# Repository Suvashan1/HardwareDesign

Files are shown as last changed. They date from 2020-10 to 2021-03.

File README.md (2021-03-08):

# STM32 Breakout-Board using STM32F103C8T6 Microcontroller

Using this medium-density microcontroller, an experimental peripheral board was designed using KiCAD to validate PCB design principles that I have learnt. It has formed a template for future layouts and schematic designs. For further information on my design choices, method and components selected and their placement, please read the design-considerations PDF in the file.

# Layout:

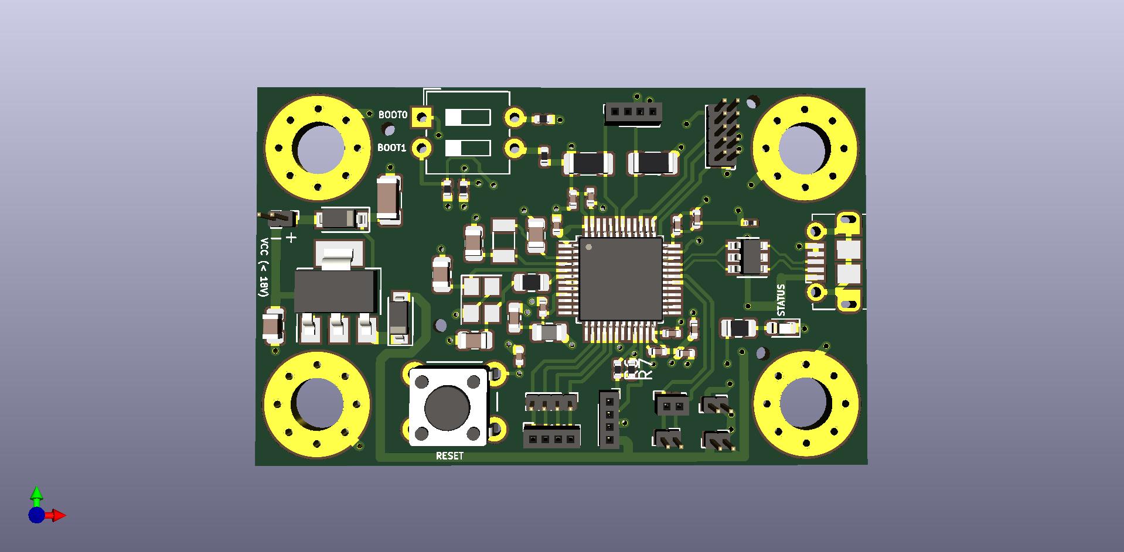
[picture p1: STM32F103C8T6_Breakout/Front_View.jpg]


# Schematic:

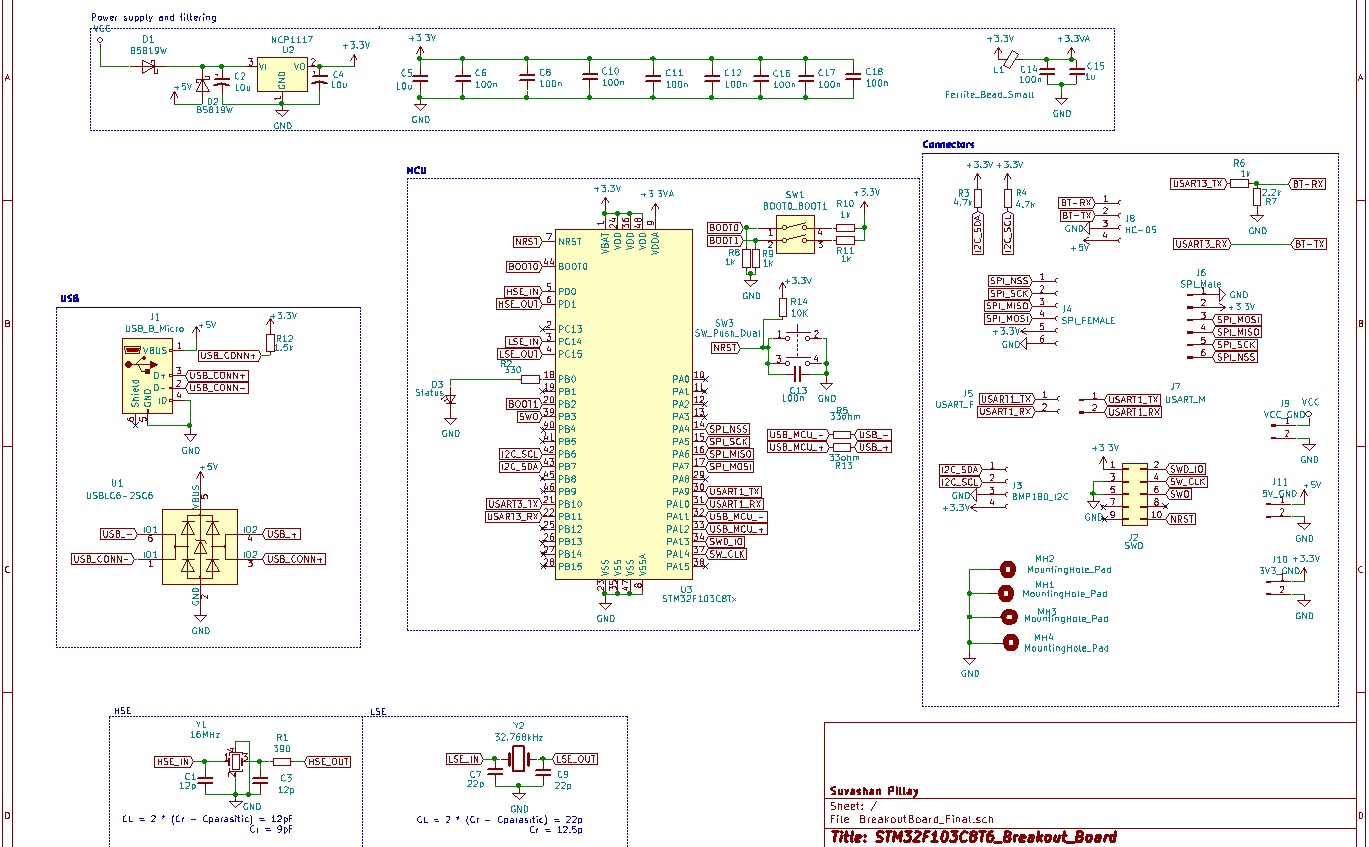
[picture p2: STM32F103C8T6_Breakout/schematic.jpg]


# BOSCH BMP180 Drivers

The following device drivers were developed to be used with the respective breakout board designed, to test the I2C interface. All instructions and files can be found in the folder
added.

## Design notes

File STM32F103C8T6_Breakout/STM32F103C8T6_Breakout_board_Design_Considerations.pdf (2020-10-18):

## STM32F103C8T6 Breakout board

### Aim

The purpose of the breakout board is to implement and/or tailor the firmware written in the "Driversfor-STM32-MCUs" repository (https://github.com/Suvashan1/Drivers-for-STM32-MCUs) on another microcontroller from ST Microelectronics and interface calibrated sensors such as the BMP180 pressure and temperature sensor, with communications interfaces. I have also aimed to present my skills in PCB (printed circuit board) design and assess my shortcomings as an engineer, to provide hardware design which is more efficient in future revisions. It is a PCB constructed entirely from scratch and serves to provide the same use as an Arduino nano or STM32 blue-pill, which are popular development boards used for prototyping with sensors.

### Microcontroller used and core components

- STM32F103C8T6 microcontroller from ST microelectronics – This microcontroller had been used, as it provides an adequate amount of basic communication peripherals (2 I2C peripherals of which 1 was used, 2 USART peripherals of which both were used, and 2 SPI peripherals of which 1 was used). These communication peripherals will allow adequate testing of the firmware written. Other interfaces such as CAN and I2S are usable on the microcontroller, for later revisions.
This series of microcontrollers are known as “mainstream performance line” by ST, as they use an ARM Cortex M3 processor, which is adequate for general usage, and cost-effective. Other microcontrollers were considered such as the STM32F407VGT6, which is native to the drivers already written, but are more expensive and requires more design considerations.
A USB 2.0 FS interface is also available on this microcontroller, allowing for USB further, but non-reliant, firmware development in the future. Essentially, one can still power the board and program it, without the use of USB, since there is provision for BOOTx (x = 1,2) mode changes. The board can be programmed via SWD (Serial-wire debug), which is an interface that has been accounted for.
- Power supply section and filtering – A 3.3V regulator (AMS1117) was used, for voltage supply of the microcontroller, from an input supply pin (allowing an input voltage from the user up to 18V). A Schottky diode was added at the input line of the regulator, and prevents any reverse bias connection, from the input supply, and an additional diode was added from a 5V line of the USB port.
According to the hardware design application note from ST (AN2586), one (typically two, as per consideration of further noise suppression) 100nF capacitor must be added for each VDD pin and a 10uF capacitor. Since we consider three VDD pins and a VBat (battery connection for the microcontroller, which should be connected to VDD if a battery is not intended), nine capacitors have been added, as a decoupling network. Decoupling and filtering for the VDDA(ADC voltage supply), had been considered, and referenced from AN2586. A ferrite bead has been added (600Ω @ 100MHz), with decoupling 100nF and 1uF capacitors, in connection to the VDD pin.
- USB implementation and ESD protection – Since USB functionality had been added, a USB-B micro had been chosen for aesthetic and size considerations. ESD protection has been added using a USBLC6-2SC6 IC. This prevents static discharge through the board.

- HSE (High-Speed External) and LSE (Low-Speed External) crystal oscillators – Both crystals (16MHz and 32.768kHz respectively) have been added, and their respective load capacitors added. Calculations of the capacitor values have been added on the schematic sheet, where the parasitic capacitance of the board had been chosen as 2pF. The LSE crystal allows the use of the RTC (Real-Time Clock) peripheral at another stage of development.
- BOOTx modes and RESET button – A 2-pole dip switch has been added to alter BOOT1 (PB2) and BOOT0 has been added. This allows the use of DFU Mode (Direct-Firmware Upgrade), where the microcontroller may be programmed directly by USART. The most popular mode of programming an ST microcontroller, is by using SWD, which is the alternative to DFU mode. A reset button has been added to provide an option to perform a hard reset on the microcontroller.

### Design considerations when drawing the schematic and component layout

- JLCPCB was the chosen fabrication service (PCBway was also considered but proved to be more expensive). A board of dimensions 50x50mm has a price of $5(R82) for a 4-layer PCB. Boards with larger dimensions fare worse in terms of cost, even if exceeded by 1mm. However, a larger board is never recommended, especially dealing with communications peripherals. A 50x31mm (L X B) board size has been used.
- Crystal oscillators, decoupling capacitors and USB had been placed closer to the microcontroller, than other peripherals. This prevents any harmonics from affecting those peripherals or the microcontroller. Schottky diodes of the power supply section specifically had also been placed further from the crystal oscillators, to prevent harmonics and electrical noise.
- A “drive-resistor” is added to the output pin of the HSE crystal oscillator on the microcontroller, to prevent the output pin from sinking excessive amounts of current and “over-driving” the crystal oscillator.
- Header pins of peripherals have been included, as close to the microcontroller as possible, and on the respective edges of their pins on the microcontroller.
- Components which could be recalculated and replaced if the peripheral proves to be problematic have been assigned larger PCB footprints, to provide easier reflow and handsoldering. Examples of these can be seen in the pcbnew file, where 1206 pull-up resistors have been used for the I2C peripheral, as the speed of the peripheral is influenced by these resistors and may be replaced. Through experimentation, 2.2kΩ and 4.7kΩ are standard values. The drive-resistor of the HSE crystal oscillator may also be replaced if the crystal cannot sustain oscillations. This may be monitored in software.
- An additional USART peripheral has been added to provide usage of the HC-05 bluetooth module (https://www.robotics.org.za/HC05-PINS), and the I2C peripheral uses a 4-pin header for the use of a BMP180 (https://www.mantech.co.za/ProductInfo.aspx?Item=15M2316) pressure sensor. These peripherals have been accounted for, to provide simplistic yet thorough testing. The HC-05 will be used to receive commands from a smartphone via Bluetooth and transmission of pressure readings from the BMP180 sensor may be processed, either transmission to the smartphone or using printf statement in the IDE.
- The 10-pin header chosen for use of the SWD interface, is to be used with a STM32F407VG-DISC1 development board which I own. This development board will serve as debugging probe via ST-LINK and allow for programming and debugging of the microcontroller.

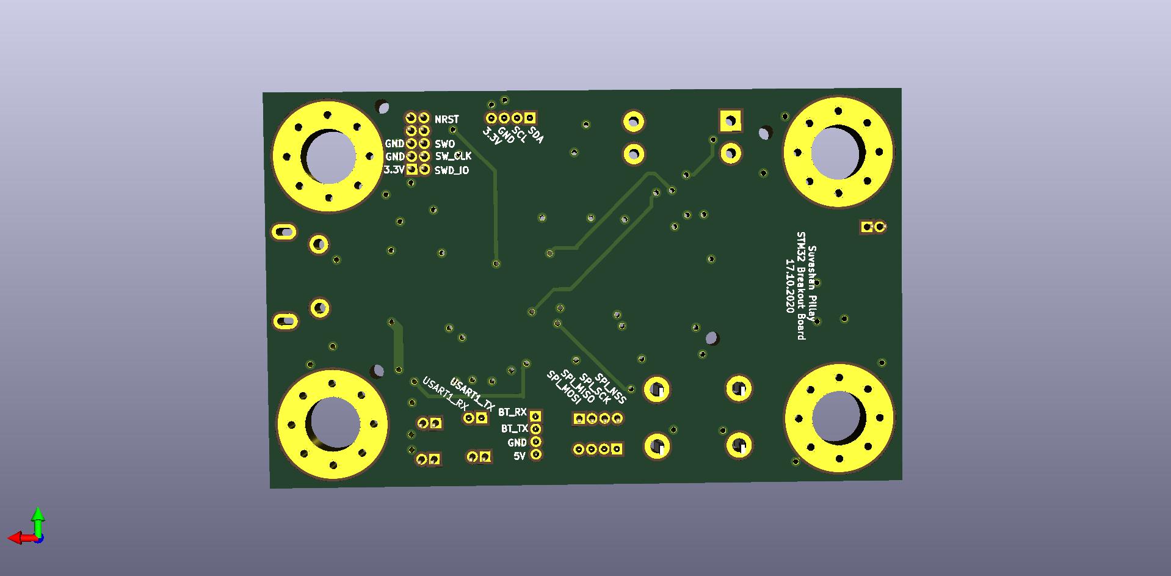
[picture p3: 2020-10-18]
STM32F103C8T6_Breakout/Rear_View.jpg

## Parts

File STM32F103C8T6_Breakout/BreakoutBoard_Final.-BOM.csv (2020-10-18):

Reference | Quantity | Value | Footprint | Datasheet | LCSC Part #
C15 | 1 | 1u | Capacitor_SMD:C_0603_1608Metric | ~ | C15849
C2 | 1 | 10u | Capacitor_SMD:C_1206_3216Metric | ~ | C13585
C1 C3 | 2 | 12p | Capacitor_SMD:C_0805_2012Metric | ~ | C1792
C4 | 1 | 10u | Capacitor_SMD:C_0805_2012Metric | ~ | C15850
C5 | 1 | 10u | Capacitor_SMD:C_0402_1005Metric | ~ | C15525
C10 C11 C12 C13 C14 C16 C17 C18 C6 C8 | 10 | 100n | Capacitor_SMD:C_0402_1005Metric | ~ | C1525
C7 C9 | 2 | 22p | Capacitor_SMD:C_0805_2012Metric | ~ | C1804
D1 D2 | 2 | B5819W | Diode_SMD:D_SOD-123 | ~ | C8598
D3 | 1 | Status | LED_SMD:LED_0603_1608Metric | ~ | C72041
J1 | 1 | USB_B_Micro | Connector_USB:USB_Micro-B_Molex-105017-0001 | ~
J10 | 1 | 3V3_GND | Connector_PinHeader_1.00mm:PinHeader_1x02_P1.00mm_Vertical | ~
J11 | 1 | 5V_GND | Connector_PinHeader_1.00mm:PinHeader_1x02_P1.00mm_Vertical | ~
J2 | 1 | SWD | Connector_PinHeader_1.00mm:PinHeader_2x05_P1.00mm_Vertical | ~
J3 | 1 | BMP180_I2C | Connector_PinSocket_1.00mm:PinSocket_1x04_P1.00mm_Vertical | ~
J4 | 1 | SPI_F | Connector_PinSocket_1.00mm:PinSocket_1x04_P1.00mm_Vertical | ~
J5 | 1 | USART_F | Connector_PinSocket_1.00mm:PinSocket_1x02_P1.00mm_Vertical | ~
J6 | 1 | SPI_M | Connector_PinHeader_1.00mm:PinHeader_1x04_P1.00mm_Vertical | ~
J7 | 1 | USART_M | Connector_PinHeader_1.00mm:PinHeader_1x02_P1.00mm_Vertical | ~
J8 | 1 | HC-05 | Connector_PinSocket_1.00mm:PinSocket_1x04_P1.00mm_Vertical | ~
J9 | 1 | VCC_GND | Connector_PinHeader_1.00mm:PinHeader_1x02_P1.00mm_Vertical | ~
L1 | 1 | Ferrite_Bead_Small | Inductor_SMD:L_0805_2012Metric | ~ | C1017
MH1 MH2 MH3 MH4 | 4 | MountingHole_Pad | MountingHole:MountingHole_4.3mm_M4_Pad_Via | ~
R1 | 1 | 390 | Resistor_SMD:R_0805_2012Metric | ~ | C17655
R12 | 1 | 1.5k | Resistor_SMD:R_0201_0603Metric | ~ | C22483
R2 | 1 | 33ohm | Resistor_SMD:R_0805_2012Metric | ~ | C17634
R3 R4 | 2 | 4.7k | Resistor_SMD:R_1206_3216Metric | ~ | C17936
R10 R11 R6 R8 R9 | 5 | 1k | Resistor_SMD:R_0402_1005Metric | ~ | C11702
R7 | 1 | 2.2k | Resistor_SMD:R_0402_1005Metric | ~ | C25879
SW1 | 1 | BOOT0_BOOT1 | Button_Switch_THT:SW_DIP_SPSTx02_Slide_6.7x6.64mm_W7.62mm_P2.54mm_LowProfile
SW3 | 1 | SW_Push_Dual | Button_Switch_THT:SW_PUSH_6mm
U1 | 1 | USBLC6-2SC6 | Package_TO_SOT_SMD:SOT-23-6 | http://www2.st.com/resource/en/datasheet/CD00050750.pdf | C7519
U2 | 1 | NCP1117 | Package_TO_SOT_SMD:SOT-223-3_TabPin2 | http://www.onsemi.com/pub_link/Collateral/NCP1117-D.PDF | C6186
U3 | 1 | STM32F103C8Tx | Package_QFP:LQFP-48_7x7mm_P0.5mm | http://www.st.com/st-web-ui/static/active/en/resource/technical/document/datasheet/CD00161566.pdf | C8734
Y1 | 1 | 16MHz | Crystal:Crystal_SMD_3225-4Pin_3.2x2.5mm | ~ | C13738
Y2 | 1 | 32.768kHz | Crystal:Crystal_SMD_3215-2Pin_3.2x1.5mm | ~ | C32346

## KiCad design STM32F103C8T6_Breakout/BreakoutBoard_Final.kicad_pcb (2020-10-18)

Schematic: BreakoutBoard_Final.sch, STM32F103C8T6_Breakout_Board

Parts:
C1, C3: 12p; C_0805_2012Metric; LCSC Part # C1792
C2: 10u; C_1206_3216Metric; LCSC Part # C13585
C4: 10u; C_0805_2012Metric; LCSC Part # C15850
C5: 10u; C_0402_1005Metric; LCSC Part # C15525
C6, C8, C10, C11, C12, C13, C14, C16, C17, C18: 100n; C_0402_1005Metric; LCSC Part # C1525
C7, C9: 22p; C_0805_2012Metric; LCSC Part # C1804
C15: 1u; C_0603_1608Metric; LCSC Part # C15849
D1, D2: B5819W; D_SOD-123; LCSC Part # C8598
D3: Status; LED_0603_1608Metric; LCSC Part # C72041
J1: USB_B_Micro; USB_Micro-B_Molex-105017-0001
J2: SWD; PinHeader_2x05_P1.00mm_Vertical
J3: BMP180_I2C; PinSocket_1x04_P1.00mm_Vertical
J4: SPI_F; PinSocket_1x04_P1.00mm_Vertical
J5: USART_F; PinSocket_1x02_P1.00mm_Vertical
J6: SPI_M; PinHeader_1x04_P1.00mm_Vertical
J7: USART_M; PinHeader_1x02_P1.00mm_Vertical
J8: HC-05; PinSocket_1x04_P1.00mm_Vertical
J9: VCC_GND; PinHeader_1x02_P1.00mm_Vertical
J10: 3V3_GND; PinHeader_1x02_P1.00mm_Vertical
J11: 5V_GND; PinHeader_1x02_P1.00mm_Vertical
L1: Ferrite_Bead_Small; L_0805_2012Metric; LCSC Part # C1017
MH1, MH2, MH3, MH4: MountingHole_Pad; MountingHole_4.3mm_M4_Pad_Via
R1: 390; R_0805_2012Metric; LCSC Part # C17655
R2: 33ohm; R_0805_2012Metric; LCSC Part # C17634
R3, R4: 4.7k; R_1206_3216Metric; LCSC Part # C17936
R6, R8, R9, R10, R11: 1k; R_0402_1005Metric; LCSC Part # C11702
R7: 2.2k; R_0402_1005Metric; LCSC Part # C25879
R12: 1.5k; R_0201_0603Metric; LCSC Part # C22483
SW1: BOOT0_BOOT1; SW_DIP_SPSTx02_Slide_6.7x6.64mm_W7.62mm_P2.54mm_LowProfile
SW3: SW_Push_Dual; SW_PUSH_6mm
U1: USBLC6-2SC6; SOT-23-6; LCSC Part # C7519
U2: NCP1117; SOT-223-3_TabPin2; LCSC Part # C6186
U3: STM32F103C8Tx; LQFP-48_7x7mm_P0.5mm; LCSC Part # C8734
Y1: 16MHz; Crystal_SMD_3225-4Pin_3.2x2.5mm; LCSC Part # C13738
Y2: 32.768kHz; Crystal_SMD_3215-2Pin_3.2x1.5mm; LCSC Part # C32346

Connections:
+3.3VA: C14.1, C15.1, L1.1, U3.9
+3V3: C4.1, C5.1, C6.1, C8.1, C10.1, C11.1, C12.1, C16.1, C17.1, C18.1, J2.1, J3.4, J10.1, L1.2, R3.1, R4.1, R10.1, R11.1, R12.1, U2.2 (VO), U3.1, U3.24, U3.36, U3.48
+5V: D2.2, J1.1, J8.4, J11.1, U1.5
BOOT0: R8.1, SW1.1, U3.44
BOOT1: R9.1, SW1.2, U3.20
BT-RX: J8.1, R6.2, R7.2
BT-TX: J8.2, U3.22
GND: C1.2, C2.2, C3.2, C4.2, C5.2, C6.2, C7.2, C8.2, C9.2, C10.2, C11.2, C12.2, C13.1, C14.2, C15.2, C16.2, C17.2, C18.2, D3.1, J1.4, J1.5, J2.3, J2.5, J3.3, J8.3, J9.2, J10.2, J11.2, MH1.1, MH2.1, MH3.1, MH4.1, R7.1, R8.2, R9.2, SW3.2, U1.2, U2.1 (GND), U3.8, U3.23, U3.35, U3.47, Y1.2, Y1.4
HSE_IN: C1.1, U3.5, Y1.1
HSE_OUT: R1.1, U3.6
I2C_SCL: J3.2, R4.2, U3.42
I2C_SDA: J3.1, R3.2, U3.43
LSE_IN: C7.1, U3.3, Y2.1
LSE_OUT: C9.1, U3.4, Y2.2
NRST: C13.2, J2.10, SW3.1, U3.7
unnamed: C2.1, D1.1, D2.1, U2.3 (VI)
unnamed: C3.1, R1.2, Y1.3
unnamed: D3.2, R2.1
unnamed: R2.2, U3.18
unnamed: R10.2, SW1.4
unnamed: R11.2, SW1.3
SPI_MISO: J4.3, J6.2, U3.16
SPI_MOSI: J4.4, J6.1, U3.17
SPI_NSS: J4.1, J6.4, U3.14
SPI_SCK: J4.2, J6.3, U3.15
SWD_IO: J2.2, U3.34
SWO: J2.6, U3.39
SW_CLK: J2.4, U3.37
USART1_RX: J5.2, J7.2, U3.31
USART1_TX: J5.1, J7.1, U3.30
USART3_TX: R6.1, U3.21
USB_+: U1.4, U3.33
USB_-: U1.6, U3.32
USB_CONN+: J1.3, U1.3
USB_CONN-: J1.2, U1.1
USB_DP: R12.2
VCC: D1.2, J9.1

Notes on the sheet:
Power supply and filtering
CL = 2 * (Cr - Cparasitic) = 12pF Cr = 9pF
HSE
USB
Connectors
MCU
CL = 2 * (Cr - Cparasitic) = 22p Cr = 12.5p
LSE

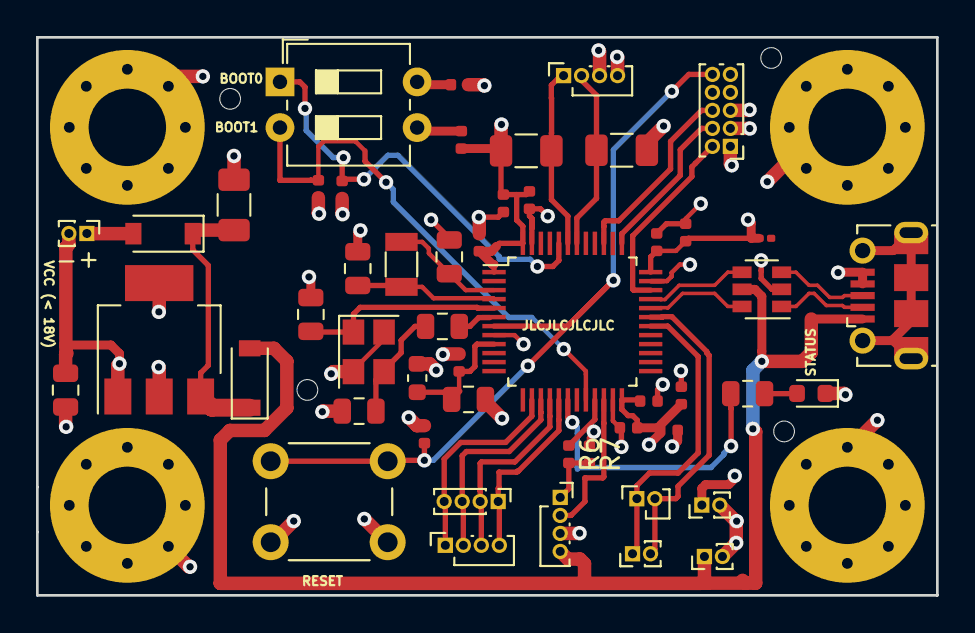
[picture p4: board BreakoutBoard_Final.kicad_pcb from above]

Board: 4 copper layers, 50.0 x 31.0 mm, 55 parts (0 on the bottom side), 36 nets.

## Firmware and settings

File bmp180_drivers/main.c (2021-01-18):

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
/* Includes ------------------------------------------------------------------*/

/*
 * The following file contains the main loop of the application to measure and display the temperature and pressure readings
 * from the BMP180. To display the data, USART3 was used. You may alter this in the main loop to display the string "buffer"
 * however you may choose. Other settings and initialisations can be removed if it is not needed such as SPI and I2S, but
 * it should not interfere with your project build.
 */


#include "main.h"
#include "usb_device.h"
#include "usbd_cdc_if.h"
#include "bmp180.h"
#include "stdio.h"
#include "stdlib.h"
#include "string.h"

I2C_HandleTypeDef hi2c1;

I2S_HandleTypeDef hi2s3;

SPI_HandleTypeDef hspi1;

UART_HandleTypeDef huart3;


void SystemClock_Config(void);
static void MX_GPIO_Init(void);
static void MX_I2C1_Init(void);
static void MX_I2S3_Init(void);
static void MX_SPI1_Init(void);
static void MX_USART3_UART_Init(void);

int main(void)
{

  HAL_Init();

  SystemClock_Config();

  MX_GPIO_Init();
  MX_I2C1_Init();
  MX_I2S3_Init();
  MX_SPI1_Init();
  MX_USART3_UART_Init();
  MX_USB_DEVICE_Init();
  /* USER CODE BEGIN 2 */

  //1. initialise the I2Cx_Handle used for communication with the device
  //2. Initialise the oversampling setting.
  bmp180_oss_i2c_init(&hi2c1, standard);

  //retrieve calibration data (this should NOT be called in the while loop)
  _get_calib_data();
  	while (1) {

	int32_t temp = _get_Temp();
	int32_t pressure = _get_Pressure();
	char buffer[100] = "";
	sprintf(buffer, "Temp: %d.%d\r\n Pressure: %d\r\n", (int)temp/10, (int)temp%10, (int)pressure);
	HAL_UART_Transmit(&huart3, buffer, strlen(buffer), 1000);
	HAL_Delay(1000);
  	}

  }


void SystemClock_Config(void)
{
  RCC_OscInitTypeDef RCC_OscInitStruct = {0};
  RCC_ClkInitTypeDef RCC_ClkInitStruct = {0};
  RCC_PeriphCLKInitTypeDef PeriphClkInitStruct = {0};

  /** Configure the main internal regulator output voltage
  */
  __HAL_RCC_PWR_CLK_ENABLE();
  __HAL_PWR_VOLTAGESCALING_CONFIG(PWR_REGULATOR_VOLTAGE_SCALE1);
  /** Initializes the RCC Oscillators according to the specified parameters
  * in the RCC_OscInitTypeDef structure.
  */
  RCC_OscInitStruct.OscillatorType = RCC_OSCILLATORTYPE_HSE;
  RCC_OscInitStruct.HSEState = RCC_HSE_ON;
  RCC_OscInitStruct.PLL.PLLState = RCC_PLL_ON;
  RCC_OscInitStruct.PLL.PLLSource = RCC_PLLSOURCE_HSE;
  RCC_OscInitStruct.PLL.PLLM = 8;
  RCC_OscInitStruct.PLL.PLLN = 336;
  RCC_OscInitStruct.PLL.PLLP = RCC_PLLP_DIV2;
  RCC_OscInitStruct.PLL.PLLQ = 7;
  if (HAL_RCC_OscConfig(&RCC_OscInitStruct) != HAL_OK)
  {
    Error_Handler();
  }
  /** Initializes the CPU, AHB and APB buses clocks
  */
  RCC_ClkInitStruct.ClockType = RCC_CLOCKTYPE_HCLK|RCC_CLOCKTYPE_SYSCLK
                              |RCC_CLOCKTYPE_PCLK1|RCC_CLOCKTYPE_PCLK2;
  RCC_ClkInitStruct.SYSCLKSource = RCC_SYSCLKSOURCE_PLLCLK;
  RCC_ClkInitStruct.AHBCLKDivider = RCC_SYSCLK_DIV1;
  RCC_ClkInitStruct.APB1CLKDivider = RCC_HCLK_DIV4;
  RCC_ClkInitStruct.APB2CLKDivider = RCC_HCLK_DIV2;

  if (HAL_RCC_ClockConfig(&RCC_ClkInitStruct, FLASH_LATENCY_5) != HAL_OK)
  {
    Error_Handler();
  }
  PeriphClkInitStruct.PeriphClockSelection = RCC_PERIPHCLK_I2S;
  PeriphClkInitStruct.PLLI2S.PLLI2SN = 192;
  PeriphClkInitStruct.PLLI2S.PLLI2SR = 2;
  if (HAL_RCCEx_PeriphCLKConfig(&PeriphClkInitStruct) != HAL_OK)
  {
    Error_Handler();
  }
}

/**
  * @brief I2C1 Initialization Function
  * @param None
  * @retval None
  */
static void MX_I2C1_Init(void)
{

  hi2c1.Instance = I2C1;
  hi2c1.Init.ClockSpeed = 100000;
  hi2c1.Init.DutyCycle = I2C_DUTYCYCLE_2;
  hi2c1.Init.OwnAddress1 = 0;
  hi2c1.Init.AddressingMode = I2C_ADDRESSINGMODE_7BIT;
  hi2c1.Init.DualAddressMode = I2C_DUALADDRESS_DISABLE;
  hi2c1.Init.OwnAddress2 = 0;
  hi2c1.Init.GeneralCallMode = I2C_GENERALCALL_DISABLE;
  hi2c1.Init.NoStretchMode = I2C_NOSTRETCH_DISABLE;
  if (HAL_I2C_Init(&hi2c1) != HAL_OK)
  {
    Error_Handler();
  }
}

/**
  * @brief I2S3 Initialization Function
  * @param None
  * @retval None
  */
static void MX_I2S3_Init(void)
{

  hi2s3.Instance = SPI3;
  hi2s3.Init.Mode = I2S_MODE_MASTER_TX;
  hi2s3.Init.Standard = I2S_STANDARD_PHILIPS;
  hi2s3.Init.DataFormat = I2S_DATAFORMAT_16B;
  hi2s3.Init.MCLKOutput = I2S_MCLKOUTPUT_ENABLE;
  hi2s3.Init.AudioFreq = I2S_AUDIOFREQ_96K;
  hi2s3.Init.CPOL = I2S_CPOL_LOW;
  hi2s3.Init.ClockSource = I2S_CLOCK_PLL;
  hi2s3.Init.FullDuplexMode = I2S_FULLDUPLEXMODE_DISABLE;
  if (HAL_I2S_Init(&hi2s3) != HAL_OK)
  {
    Error_Handler();
  }
}

/**
  * @brief SPI1 Initialization Function
  * @param None
  * @retval None
  */
static void MX_SPI1_Init(void)
{

  /* SPI1 parameter configuration*/
  hspi1.Instance = SPI1;
  hspi1.Init.Mode = SPI_MODE_MASTER;
  hspi1.Init.Direction = SPI_DIRECTION_2LINES;
  hspi1.Init.DataSize = SPI_DATASIZE_8BIT;
  hspi1.Init.CLKPolarity = SPI_POLARITY_LOW;
  hspi1.Init.CLKPhase = SPI_PHASE_1EDGE;
  hspi1.Init.NSS = SPI_NSS_SOFT;
  hspi1.Init.BaudRatePrescaler = SPI_BAUDRATEPRESCALER_2;
  hspi1.Init.FirstBit = SPI_FIRSTBIT_MSB;
  hspi1.Init.TIMode = SPI_TIMODE_DISABLE;
  hspi1.Init.CRCCalculation = SPI_CRCCALCULATION_DISABLE;
  hspi1.Init.CRCPolynomial = 10;
  if (HAL_SPI_Init(&hspi1) != HAL_OK)
  {
    Error_Handler();
  }
}

/**
  * @brief USART3 Initialization Function
  * @param None
  * @retval None
  */
static void MX_USART3_UART_Init(void)
{

  huart3.Instance = USART3;
  huart3.Init.BaudRate = 115200;
  huart3.Init.WordLength = UART_WORDLENGTH_8B;
  huart3.Init.StopBits = UART_STOPBITS_1;
  huart3.Init.Parity = UART_PARITY_NONE;
  huart3.Init.Mode = UART_MODE_TX_RX;
  huart3.Init.HwFlowCtl = UART_HWCONTROL_NONE;
  huart3.Init.OverSampling = UART_OVERSAMPLING_16;
  if (HAL_UART_Init(&huart3) != HAL_OK)
  {
    Error_Handler();
  }
}

/**
  * @brief GPIO Initialization Function
  * @param None
  * @retval None
  */
static void MX_GPIO_Init(void)
{
  GPIO_InitTypeDef GPIO_InitStruct = {0};

  /* GPIO Ports Clock Enable */
  __HAL_RCC_GPIOE_CLK_ENABLE();
  __HAL_RCC_GPIOC_CLK_ENABLE();
  __HAL_RCC_GPIOH_CLK_ENABLE();
  __HAL_RCC_GPIOA_CLK_ENABLE();
  __HAL_RCC_GPIOB_CLK_ENABLE();
  __HAL_RCC_GPIOD_CLK_ENABLE();

  /*Configure GPIO pin Output Level */
  HAL_GPIO_WritePin(CS_I2C_SPI_GPIO_Port, CS_I2C_SPI_Pin, GPIO_PIN_RESET);

  /*Configure GPIO pin Output Level */
  HAL_GPIO_WritePin(OTG_FS_PowerSwitchOn_GPIO_Port, OTG_FS_PowerSwitchOn_Pin, GPIO_PIN_SET);

  /*Configure GPIO pin Output Level */
  HAL_GPIO_WritePin(GPIOD, LD4_Pin|LD3_Pin|LD5_Pin|LD6_Pin
                          |Audio_RST_Pin, GPIO_PIN_RESET);

  /*Configure GPIO pin : CS_I2C_SPI_Pin */
  GPIO_InitStruct.Pin = CS_I2C_SPI_Pin;
  GPIO_InitStruct.Mode = GPIO_MODE_OUTPUT_PP;
  GPIO_InitStruct.Pull = GPIO_NOPULL;
  GPIO_InitStruct.Speed = GPIO_SPEED_FREQ_LOW;
  HAL_GPIO_Init(CS_I2C_SPI_GPIO_Port, &GPIO_InitStruct);

  /*Configure GPIO pin : OTG_FS_PowerSwitchOn_Pin */
  GPIO_InitStruct.Pin = OTG_FS_PowerSwitchOn_Pin;
  GPIO_InitStruct.Mode = GPIO_MODE_OUTPUT_PP;
  GPIO_InitStruct.Pull = GPIO_NOPULL;
  GPIO_InitStruct.Speed = GPIO_SPEED_FREQ_LOW;
  HAL_GPIO_Init(OTG_FS_PowerSwitchOn_GPIO_Port, &GPIO_InitStruct);

  /*Configure GPIO pin : PDM_OUT_Pin */
  GPIO_InitStruct.Pin = PDM_OUT_Pin;
  GPIO_InitStruct.Mode = GPIO_MODE_AF_PP;
  GPIO_InitStruct.Pull = GPIO_NOPULL;
  GPIO_InitStruct.Speed = GPIO_SPEED_FREQ_LOW;
  GPIO_InitStruct.Alternate = GPIO_AF5_SPI2;
  HAL_GPIO_Init(PDM_OUT_GPIO_Port, &GPIO_InitStruct);

  /*Configure GPIO pin : B1_Pin */
  GPIO_InitStruct.Pin = B1_Pin;
  GPIO_InitStruct.Mode = GPIO_MODE_EVT_RISING;
  GPIO_InitStruct.Pull = GPIO_NOPULL;
  HAL_GPIO_Init(B1_GPIO_Port, &GPIO_InitStruct);

  /*Configure GPIO pin : BOOT1_Pin */
  GPIO_InitStruct.Pin = BOOT1_Pin;
  GPIO_InitStruct.Mode = GPIO_MODE_INPUT;
  GPIO_InitStruct.Pull = GPIO_NOPULL;
  HAL_GPIO_Init(BOOT1_GPIO_Port, &GPIO_InitStruct);

  /*Configure GPIO pin : CLK_IN_Pin */
  GPIO_InitStruct.Pin = CLK_IN_Pin;
  GPIO_InitStruct.Mode = GPIO_MODE_AF_PP;
  GPIO_InitStruct.Pull = GPIO_NOPULL;
  GPIO_InitStruct.Speed = GPIO_SPEED_FREQ_LOW;
  GPIO_InitStruct.Alternate = GPIO_AF5_SPI2;
  HAL_GPIO_Init(CLK_IN_GPIO_Port, &GPIO_InitStruct);

  /*Configure GPIO pins : LD4_Pin LD3_Pin LD5_Pin LD6_Pin
                           Audio_RST_Pin */
  GPIO_InitStruct.Pin = LD4_Pin|LD3_Pin|LD5_Pin|LD6_Pin
                          |Audio_RST_Pin;
  GPIO_InitStruct.Mode = GPIO_MODE_OUTPUT_PP;
  GPIO_InitStruct.Pull = GPIO_NOPULL;
  GPIO_InitStruct.Speed = GPIO_SPEED_FREQ_LOW;
  HAL_GPIO_Init(GPIOD, &GPIO_InitStruct);

  /*Configure GPIO pin : OTG_FS_OverCurrent_Pin */
  GPIO_InitStruct.Pin = OTG_FS_OverCurrent_Pin;
  GPIO_InitStruct.Mode = GPIO_MODE_INPUT;
  GPIO_InitStruct.Pull = GPIO_NOPULL;
  HAL_GPIO_Init(OTG_FS_OverCurrent_GPIO_Port, &GPIO_InitStruct);

  /*Configure GPIO pin : MEMS_INT2_Pin */
  GPIO_InitStruct.Pin = MEMS_INT2_Pin;
  GPIO_InitStruct.Mode = GPIO_MODE_EVT_RISING;
  GPIO_InitStruct.Pull = GPIO_NOPULL;
  HAL_GPIO_Init(MEMS_INT2_GPIO_Port, &GPIO_InitStruct);

}

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


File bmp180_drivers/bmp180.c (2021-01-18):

/*
 * bmp180.c
 *
 *  Created on: Jan 7, 2021
 *      Author: Suvashan
 */

#include "bmp180.h"
#include "math.h"

//Create variables for the oversampling setting, calibration co-efficients and I2C handle
BMP180_OSS oss;
BMP180_calib calib;
I2C_HandleTypeDef *i2c;


const uint8_t  temp_ctrl = 0x2E;
const uint8_t temp_delay = 5;
const uint8_t press_ctrl[4] = {0x34, 0x74, 0xB4, 0xF4};
const uint8_t press_delay[4] = {5, 8, 14, 26};

const uint8_t bmp180_reg_addr_MSB[11] = {0xaa, 0xac, 0xae, 0xb0, 0xb2, 0xb4, 0xb6, 0xb8, 0xba, 0xbc, 0xbe};
const uint8_t bmp180_reg_addr_LSB[11] = {0xab, 0xad, 0xaf, 0xb1, 0xb3, 0xb5, 0xb7, 0xb9, 0xbb, 0xbd, 0xbf};



static void writeData(uint8_t reg, uint8_t data){

	uint8_t arr[2] = {reg, data};

	HAL_I2C_Master_Transmit(i2c, (BMP180_I2C_ADDR << 1), arr, 2, 1000);
}

static uint8_t readData(uint8_t reg){

		HAL_I2C_Master_Transmit(i2c, (BMP180_I2C_ADDR << 1) , &reg, 1, 1000);
		uint8_t data = 0;
		HAL_I2C_Master_Receive(i2c, (BMP180_I2C_ADDR << 1) , &data, 1, 1000);
		return data;
}

/**
 * @brief Retrieves calibration data
 *
 */
void _get_calib_data(void){

	calib.AC1 = (readData(bmp180_reg_addr_MSB[AC1_INDEX]) << 8) | readData(bmp180_reg_addr_LSB[AC1_INDEX]);
	calib.AC2 = (readData(bmp180_reg_addr_MSB[AC2_INDEX]) << 8) | readData(bmp180_reg_addr_LSB[AC2_INDEX]);
	calib.AC3 = (readData(bmp180_reg_addr_MSB[AC3_INDEX]) << 8) | readData(bmp180_reg_addr_LSB[AC3_INDEX]);
	calib.AC4 = (readData(bmp180_reg_addr_MSB[AC4_INDEX]) << 8) | readData(bmp180_reg_addr_LSB[AC4_INDEX]);
	calib.AC5 = (readData(bmp180_reg_addr_MSB[AC5_INDEX]) << 8) | readData(bmp180_reg_addr_LSB[AC5_INDEX]);
	calib.AC6 = (readData(bmp180_reg_addr_MSB[AC6_INDEX]) << 8) | readData(bmp180_reg_addr_LSB[AC6_INDEX]);
	calib.B1 = (readData(bmp180_reg_addr_MSB[B1_INDEX]) << 8) | readData(bmp180_reg_addr_LSB[B1_INDEX]);
	calib.B2 = (readData(bmp180_reg_addr_MSB[B2_INDEX]) << 8) | readData(bmp180_reg_addr_LSB[B2_INDEX]);
	calib.MB = (readData(bmp180_reg_addr_MSB[MB_INDEX]) << 8) | readData(bmp180_reg_addr_LSB[MB_INDEX]);
	calib.MC = (readData(bmp180_reg_addr_MSB[MC_INDEX]) << 8) | readData(bmp180_reg_addr_LSB[MC_INDEX]);
	calib.MD = (readData(bmp180_reg_addr_MSB[MD_INDEX]) << 8) | readData(bmp180_reg_addr_LSB[MD_INDEX]);
}

/**
 * @brief Initialises the I2C Handle for the respective I2Cx peripheral, and the oversampling setting
 * @param bmp180_i2c pointer to the I2C Handle
 * @param bmp180_oss oversampling setting (options: ultraLP, standard, highRes, ultraHigh)
 */
void bmp180_oss_i2c_init(I2C_HandleTypeDef *bmp180_i2c, BMP180_OSS bmp180_oss){

	i2c = bmp180_i2c;
	oss = bmp180_oss;
}

/**
 * @brief calculates the temperature(in degrees celsius) based on the logic and mathematics given in BMP180 datasheet
 * @return temperature value
 */

int32_t _get_Temp(void){

	writeData(BMP180_CTRL_REG, temp_ctrl);
	HAL_Delay(temp_delay);
	long uncompT = (readData(BMP180_MSB) << 8) | (readData(BMP180_LSB));
	long X1 = (uncompT - calib.AC6) * calib.AC5/(1<<15);
	long X2 = (calib.MC * (1 << 11))/(X1 + calib.MD);
	long B5 = X1 + X2;
	return (B5+8)/ (1 << 4);
}

/**
 * @brief calculates the pressure(in Pa) based on the logic and mathematics given in BMP180 datasheet
 * @return pressure value
 */
int32_t _get_Pressure(void){
	writeData(BMP180_CTRL_REG, temp_ctrl);
	HAL_Delay(temp_delay);
	int32_t tempUT = bmp180_getUT();
	writeData(BMP180_CTRL_REG, press_ctrl[oss]);
	HAL_Delay(press_delay[oss]);
	int32_t tempUP = bmp180_getUP();
	long X1 = (tempUT - calib.AC6) * calib.AC5/(1<<15);
	long X2 = (calib.MC * (1 << 11))/(X1 + calib.MD);
	long B5 = X1 + X2;
	long B6 = B5 - 4000;
	X1 = (calib.B2 * (B6 * B6 / (1 << 12))) / (1 << 11);
	X2 = calib.AC2 * B6/ (1 << 11);
	long X3 = X1 + X2;
	long B3 = (((calib.AC1 * 4 + X3) << oss)  + 2) / (1 << 2);
	X1 = calib.AC3 * B6 / (1 << 15);
	X2 = (calib.B1 * (B6 * B6 / (1 << 12))) / (1 << 16);
	X3 = ((X1 + X2) + 2) / 4;
	uint32_t  B4 = calib.AC4 * (uint32_t)(X3 + 32768) / (1 << 15);
	uint32_t B7 = ((uint32_t)tempUP - B3) * (50000 >> oss);
	int32_t p;
	if (B7 < 0x80000000){
		p = (B7 * 2) / B4;
	}
	else{
		p = (B7/B4) * 2;
	}

	X1 = (p/(1 << 8)) * (p/(1 << 8));
	X1 = (X1 * 3038) / (1 << 16);
	X2 = (-7357 * p)/ (1 << 16);
	p = p + (X1 + X2 + 3791)/ (1 << 4);
	return p;
}

static int32_t bmp180_getUT(void){
	return (readData(BMP180_MSB) << 8) | readData(BMP180_LSB);
}

static int32_t bmp180_getUP(void){

	return ((readData(BMP180_MSB) << 16) | (readData(BMP180_LSB) << 8) | readData(BMP180_XLSB)) >> (8 - oss);

}

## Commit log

2020-10-18 Initial commit
    Initial PCB design of STM32F103C8T6 breakout board
    [BreakoutBoard_Final.-BOM.csv, BreakoutBoard_Final.-BOM.xlsx, BreakoutBoard_Final.kicad_pcb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]
2021-01-18 BOSCH BMP180 Device drivers added

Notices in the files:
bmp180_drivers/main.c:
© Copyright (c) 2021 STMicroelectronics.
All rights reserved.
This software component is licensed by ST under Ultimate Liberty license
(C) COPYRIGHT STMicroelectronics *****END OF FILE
